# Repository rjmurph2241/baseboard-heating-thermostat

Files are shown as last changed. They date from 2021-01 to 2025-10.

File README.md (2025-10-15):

# ESPHome Based Line Voltage (Baseboard Heating) Thermostat From Wall Switch
A while back, I wanted to add smart thermostats to my apartment.  However, I was surprised by the lack of inexpensive, line voltage (or baseboard) smart thermostats.  Especially since there's so many cheap smart wall switches, and a line voltage thermostat is just a wall switch with a temperature sensor and some type of UI.  So I decided to make some using [ESPHome](esphome.io) and [Home Assistant](home-assistant.io).  At the time, most smart switches used an ESP8266 so I designed a thermostat that could take advantage of the microcontroller that came with the switch.  I've since moved to a house with central heat but has a baseboard heater in the bathroom.  I wanted to be able to run the heater on a timer for showers in the winter so I redesigned the thermostat to use a ESP32 for the increased I/O to add buttons instead of the rotary encoder.

### A couple of notes/warnings:

1. :warning:**Warning**:warning: This project involves line voltage, which can be extremely dangerous and deadly.  I am not an electrician or electrical engineer so proceed at your own risk.  Always turn off the power at the breaker and ~~double~~ triple check the power is disconnected before touching any wires.
1. This project uses inexpensive smart switches.  They are technically rated for 10A but the quality control on the relays is probably not great, so I wouldn't recommend pushing the rating.  If you're worried or your heater is close to the rating, an option would be to replace the relay with something of higher quality.
1. Most smart switches no longer use an ESP as their microcontroller so you may have to replace the whole control board anyway.  [ESPHome](esphome.io) now supports the BK72xx and RTL87xx but I haven't played around with them at all so I have no idea if they could work.  ESPs are inexpensive so my recommendation, even for the rotary encoder version, would be to just replace the control board with your own ESP and save the headache.
1. I designed the covers in a CAD program called [Alibre Atom 3D](https://www.alibre.com/atom3d/).  It's not very widely used (I've never met anyone else who uses it) but it's functional, keeps everything local, and inexpensive.  I've uploaded the CAD files on the off-chance someone else uses Alibre, but .STP and .STL files are available on [Printables](https://www.printables.com/model/1037639-smart-baseboard-heater-thermostat).

## Instructions Here:

[**Rotary Encoder**](/rotary-encoder/Rotary-Encoder.md) | [**Six Buttons**](/six-buttons/Six-Buttons.md)
:--------------------------------------------------:|:----------------------------------------------------------:
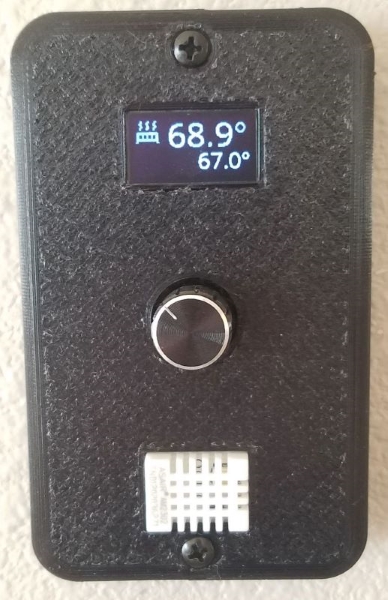
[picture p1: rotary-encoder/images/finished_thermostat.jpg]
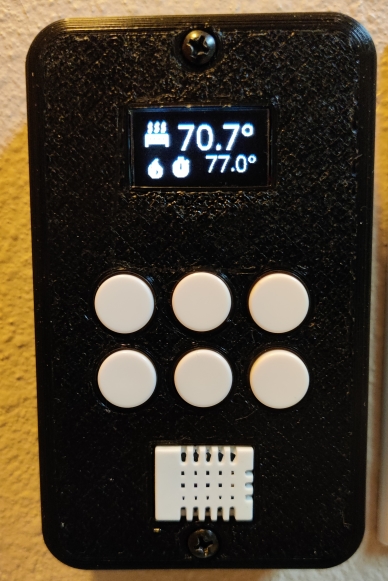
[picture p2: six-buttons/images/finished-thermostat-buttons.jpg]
  |

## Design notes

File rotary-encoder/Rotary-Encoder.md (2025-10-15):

# Rotary Encoder Thermostat from Smart Switch

## :warning:***Warning***:warning: 
***This project involves line voltage, which can be extremely dangerous and deadly.  I am not an electrician or electrical engineer so proceed at your own risk.  Always turn off the power at the breaker and ~~double~~ triple check the power is disconnected before touching any wires.***



## Parts List ##
1. A ESP based smart wall switch, with accessible GPIO pins.  I used a Laghten smart switch (no longer available).  Others will probably work as well, but most no longer use ESP microcontrollers.
1. A USB-UART (USB to TTL converter) for flashing 
1. DHT22/AM2302 ([Amazon Link](https://www.amazon.com/gp/product/B01JGNL2LM))
1. Rotary encoder with push button ([Amazon Link](https://www.amazon.com/gp/product/B08728K3YB))
1. 128X64 (0.96") SSD1306 OLED display ([Amazon Link](https://www.amazon.com/PEMENOL-Display-0-96inch-Raspberry-Microcontroller/dp/B07F3KY8NF))
1. JST battery connectors (optional)
1. A 4.7K resistor
1. 4x wire nuts (I reused the ones already in the wall)
1. 2X #6 screws for the switch
1. 3D printed case
1. Hot glue gun
1. 2X #6 x 1" decorative wall plate screws (colored to match your 3D printed case)

## Flashing ##
I recommend flashing the ESP before you start soldering parts onto it.  Unfortunately Tuya Convert no longer seems to work due to the new Tuya firmware, so you'll have to use a USB-UART converter and solder connections.  My smart switch was based on a TYWE3S and I used the Tasmota instructions available [here](https://tasmota.github.io/docs/devices/TYWE3S/) for flashing.

:warning: *Power the ESP from 3.3V on the USB-UART during flashing.* ***Do not connect line power during flashing!*** :warning:

I found it easiest to remove the entire board with the ESP from the switch to flash and solder on components.

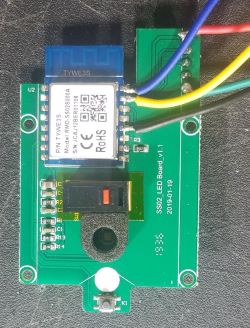
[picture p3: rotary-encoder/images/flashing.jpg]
Flashing


## Soldering Components
Here is the pinout I used.  Other configurations would likely work but I know this one worked for me.

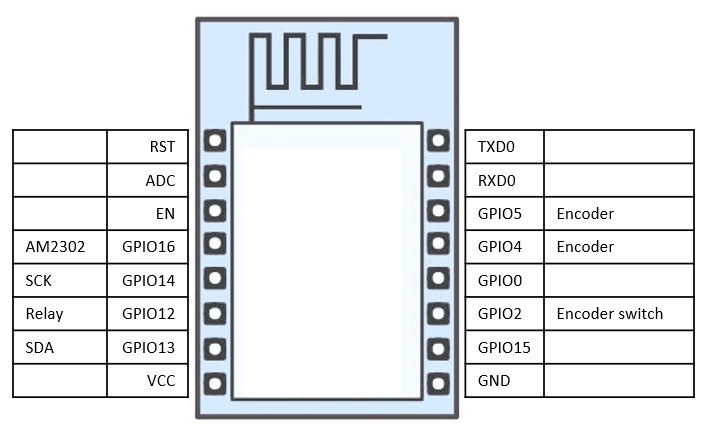
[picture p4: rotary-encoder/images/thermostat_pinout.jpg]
pinout


I also used pre-wired JST connectors to make removing the cover easier once all the components were soldered together and I used sharpie to color code the different connections.

JST Connectors

You also need to de-solder the microswitch or the encoder won't fit.  Save it along with the front plates if you ever want to change it back to a wall switch.

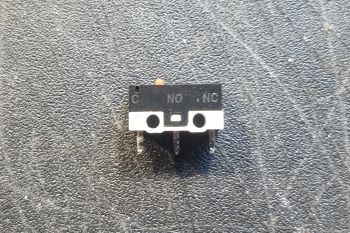
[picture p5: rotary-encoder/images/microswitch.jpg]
microswitch


### OLED Display
In order to get the OLED display to fit into the case, I de-soldered the header pins from the board and just soldered the wires directly onto the back.

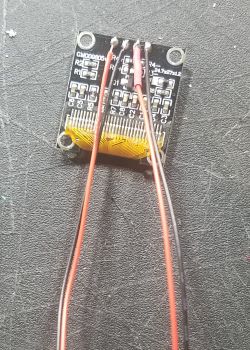
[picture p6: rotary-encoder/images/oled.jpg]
OLED


### Temperature Sensor
The AM2302 requires a pull-up resistor on the data line, so that was soldered on first along with the data wire.  Then the power wires were added.

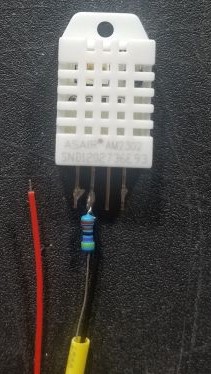
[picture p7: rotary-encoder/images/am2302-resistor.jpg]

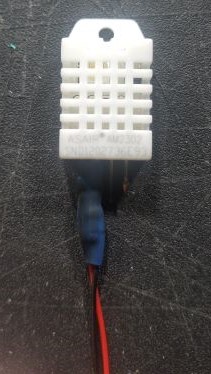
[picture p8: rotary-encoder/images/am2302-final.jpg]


You could also buy the kind that come on the circuit board, which already has the pull-up resistor.

### Rotary Encoder
The encoder has 2 separate connections.  The encoder and the push button.  For the push button, one connection should be GND and the other connected to an GPIO pin.  For the encoder portion, the center pin should be GND and the other two connected to GPIO pins.  I connected the two GND connections at the encoder and only ran one wire back to the ESP's GND.

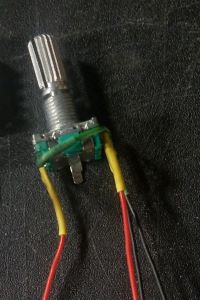
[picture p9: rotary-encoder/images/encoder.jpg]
encoder


### Case
The case was designed in Alibre Atom 3D.  I've included the [original file](/rotary-encoder/thermostat_cover_rotary_encoder.AD_PRT) as well as the .stl and STEP files (on [Printables](https://www.printables.com/model/1037639-smart-baseboard-heater-thermostat)) if anyone wants to modify them.  I printed mine on my Ender 3V2 in black PETG.  You can print it either face up or face down.  Face up requires a lot more filament for supports but gives you a better front surface.  Face down, you still need supports for where the rotary encoder goes.

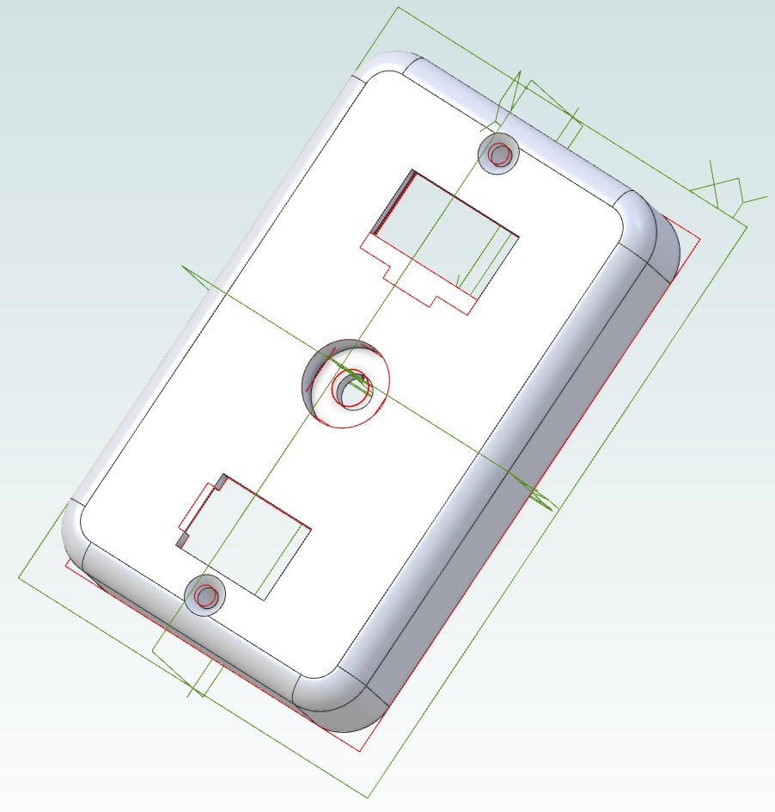
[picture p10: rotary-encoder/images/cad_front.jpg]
case


## Putting It All Together
Before gluing or closing anything up, it's always good to do a quick test to make sure all your connections are secure.

**:warning: When testing using line voltage, always put wire nuts over any unconnected wires (switched wire) and never touch any exposed connections! :warning:**

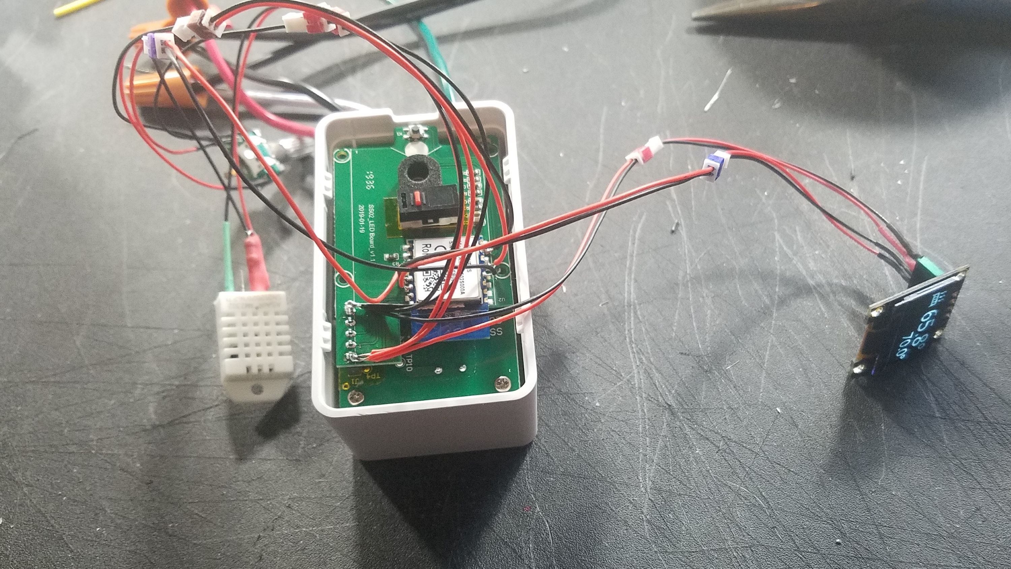
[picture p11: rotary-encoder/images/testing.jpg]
testing


(This image was taken before I realized the microswitch didn't fit.)

I like to try and make things as re-usable as possible so I prefer to use hot glue to hold everything together.  

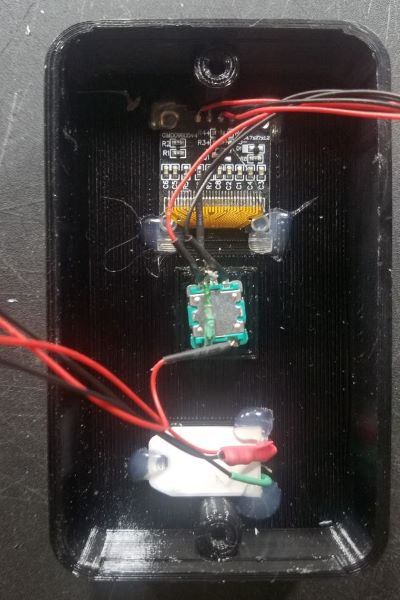
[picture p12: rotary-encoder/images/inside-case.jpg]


### Installing It On The Wall
As I am not an electrician, I don't want to give detailed instructions on how to install the high voltage aspects.  The basics of installing the thermostat are:
1. :warning: Make sure the power is turned off at the breaker :warning:
1. :warning: Check again that the power is turned off :warning:
1. :warning: Use a non-contact voltage tester to make sure theres no power! (Seriously this is important!) :warning:
1. Connect the wires appropriately.
1. Screw in the switch

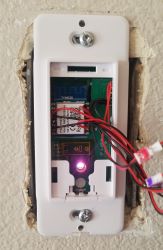
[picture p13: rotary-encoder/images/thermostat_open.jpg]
	
1. Connect the 3.3V and data cables to the components in the 3D printed case.
1. Screw on the 3D printed case
1. Cross your fingers & turn back on the power

### YAML Configuration

You'll need to set the substitutions at the top of the YAML file before you flash using ESPHome.  You'll also need to set your wifi_ssid, wifi_password, api_encryption (key) and ota_password in your secrets file.  More information on the secrets file is in the [ESPHome documentation](https://esphome.io/guides/faq.html)

## Thermostat Operation
The thermostat will work even when disconnected from Home Assistant.  
1. To change the temperature, you short press the rotary encoder and you can adjust the temperature set-point in 0.1<sup>o</sup> increments.  Another short press sets the new set-point.  If the thermostat is in "Set Temperature" mode, the thermometer icon will be displayed. 
1. To toggle the thermostat on or off, simply long press the rotary encoder. The radiator symbol will toggle between the "off" and "on" versions.  
1. The thermostat will display the flame icon while the heater is running.

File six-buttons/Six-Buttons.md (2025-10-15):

# Button Thermostat from Smart Switch

## :warning:***Warning***:warning: 
***This project involves line voltage, which can be extremely dangerous and deadly.  I am not an electrician or electrical engineer so proceed at your own risk.  Always turn off the power at the breaker and ~~double~~ triple check the power is disconnected before touching any wires.***



## Parts List ##
1. A inexpensive smart switch.
1. A ESP32 which fits in the case.  I used a D1 Mini ESP32. ([Amazon Link](https://www.amazon.com/s?k=ESP32+D1+mini))
1. DHT22/AM2302 ([Amazon Link](https://www.amazon.com/gp/product/B01JGNL2LM))
1. 6X 12x12x7.3mm momentary buttons ([Amazon Link](https://www.amazon.com/gp/product/B07CG7VTGD/))
1. Prototypeing PCB Board ([Amazon Link](https://www.amazon.com/s?k=prototype+PCB+board))
1. 128X64 (0.96") SSD1306 OLED display ([Amazon Link](https://www.amazon.com/PEMENOL-Display-0-96inch-Raspberry-Microcontroller/dp/B07F3KY8NF))
1. KF2510 Wire Connectors (Optional) ([Amazon Link](https://www.amazon.com/s?k=KF2510))
1. 4x wire nuts (I reused the ones already in the wall)
1. 2X #6 screws for the switch
1. 3D printed case
1. Hot glue gun
1. 2X #6 x 1" decorative wall plate screws (colored to match your 3D printed case)

## Soldering Components ##

### Case and ESP ###

In order to fit, the wires need to be soldered directly to the ESP without headers.  Then I used some 90<sup>o</sup> headers to connect to the 3.3V, GND, and switch I/O from the smart switch and hot-glued the ESP32 in place.

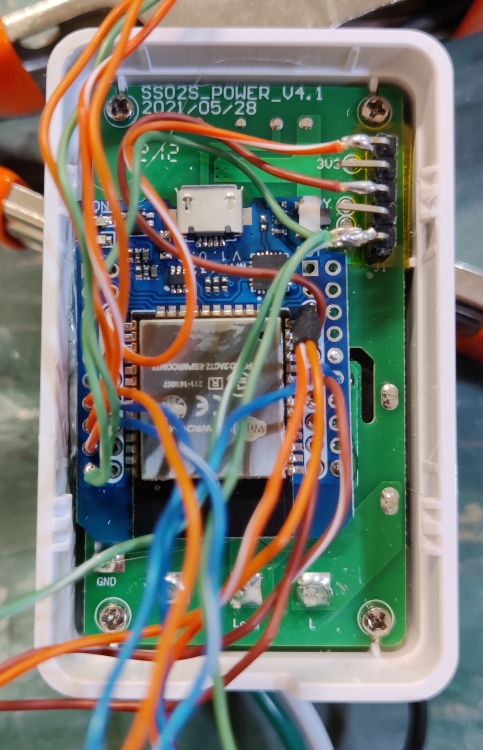
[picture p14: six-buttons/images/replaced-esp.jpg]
 

I connected the buttons, screen, and AM2302 with KF2510 connectors to make everything easy to assemble and take apart.  You could also just solder everything directly but it would probably be unwieldy.

### Buttons ###

I wired the buttons in a pull-up configuration (so they pulled to ground when pressed).  In order to fit the case they need to be soldered on a 0.6 in (15.24 mm) grid, which works out to 7 solder points center to center.

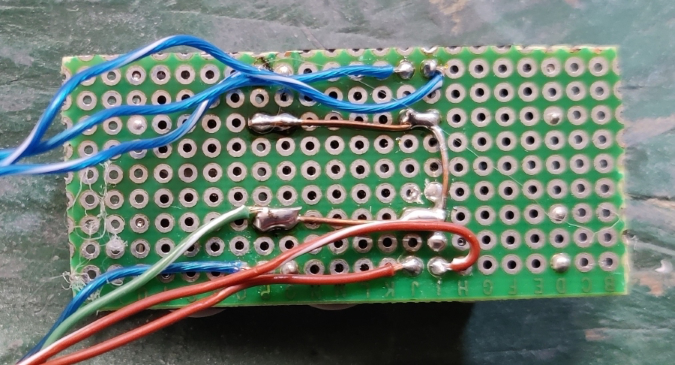
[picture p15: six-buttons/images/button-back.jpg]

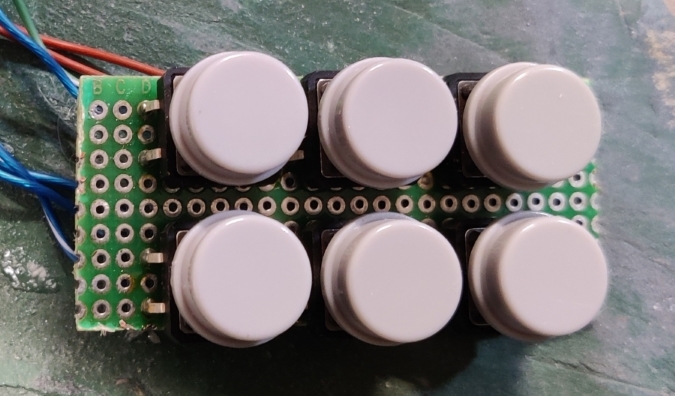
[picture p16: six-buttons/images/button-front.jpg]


### OLED Display
In order to get the OLED display to fit into the case, I de-soldered the header pins from the board and just soldered the wires directly onto the back.

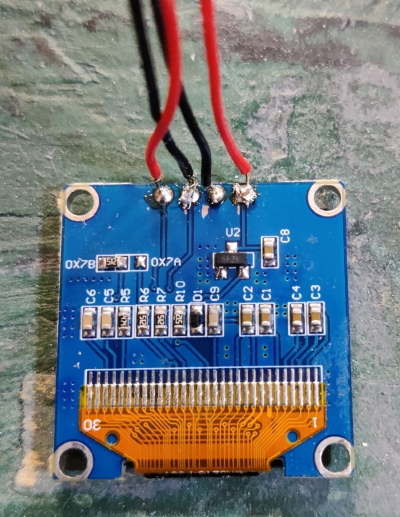
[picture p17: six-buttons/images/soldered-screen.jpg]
OLED


### Case ###
The case was designed in Alibre Atom 3D.  I've included the [original file](/six-buttons/thermostat_cover_buttons.AD_PRT) as well as the .stl and STEP files (on [Printables](https://www.printables.com/model/1037639-smart-baseboard-heater-thermostat)) if anyone wants to modify them.  I printed mine on my Ender 3 Pro in black PETG.  You can print it either face up or face down.  Face up requires a lot more filament for supports but gives you a better front surface.

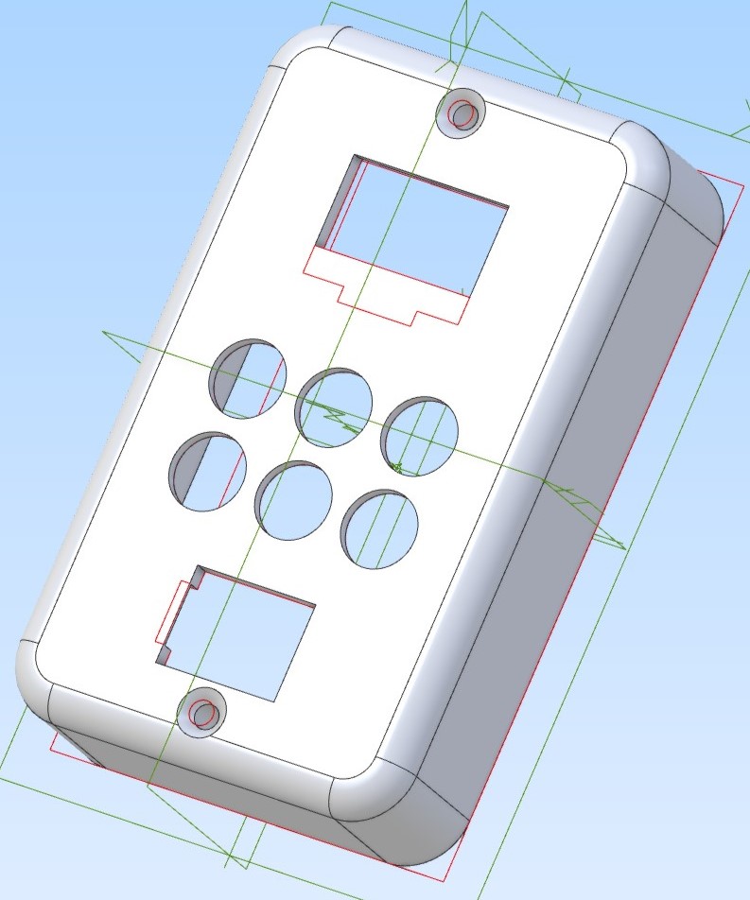
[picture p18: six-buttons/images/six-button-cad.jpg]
case


## Putting It All Together
I like to try and make things as re-usable as possible so I prefer to use hot glue to hold everything together.  

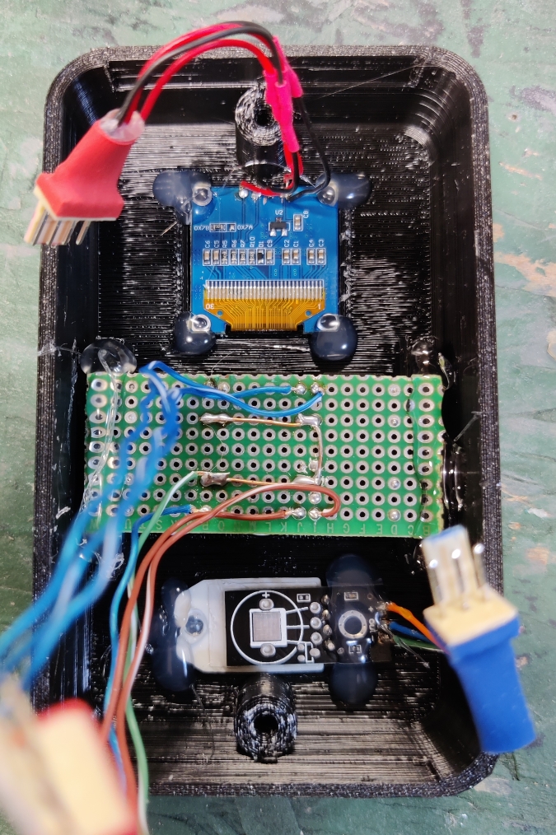
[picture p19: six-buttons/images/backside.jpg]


Before gluing or closing anything up, it's always good to do a quick test to make sure all your connections are secure.

**:warning: When testing using line voltage, always put wire nuts over any unconnected wires (switched wire) and never touch any exposed connections! :warning:**

### Installing It On The Wall
As I am not an electrician, I don't want to give detailed instructions on how to install the high voltage aspects.  The basics of installing the thermostat are:
1. :warning: Make sure the power is turned off at the breaker :warning:
1. :warning: Check again that the power is turned off :warning:
1. :warning: Use a non-contact voltage tester to make sure theres no power! (Seriously this is important!) :warning:
1. Connect the wires appropriately.
1. Screw in the switch
1. Connect the 3.3V and data cables to the components in the 3D printed case.
1. Screw on the 3D printed case
1. Cross your fingers & turn back on the power

### YAML Configuration

You'll need to set the substitutions at the top of the YAML file before you flash using ESPHome.  You'll also need to set your wifi_ssid, wifi_password, api_encryption (key) and ota_password in your secrets file.  More information on the secrets file is in the [ESPHome documentation](https://esphome.io/guides/faq.html)

## Thermostat Operation
- The thermostat will work even when disconnected from Home Assistant.  
- The large number is the current temperature and the small number is the set-point.
- The thermostat will toggle between the radiator off and radiator on symbol depending on it's state.
- The thermostat will display the flame icon while the heater is running.
- The thermostat will display the clock icon if the timer is running.

There are six buttons, I currently have them set to:

Temperature up (by 0.5 <sup>o</sup>)|Toggle On/Off|30 minute timer
:--:|:--:|:--:
**Temperature down (by 0.5 <sup>o</sup>)** | **Toggle preset (Toggle between 69<sup>o</sup> and 77<sup>o</sup> )** | **1 hour timer**

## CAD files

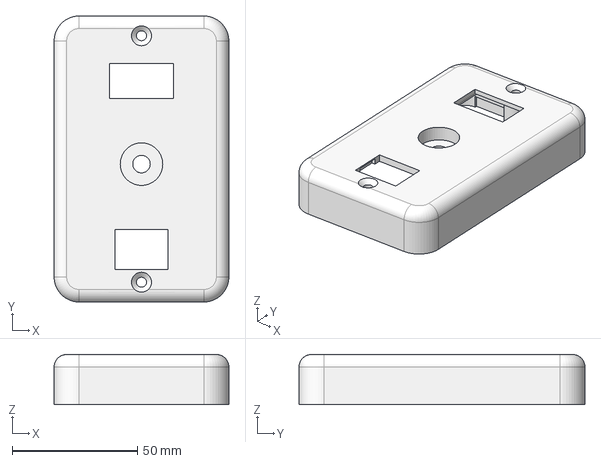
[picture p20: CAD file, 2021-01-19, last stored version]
images/thermostat cover.stp
69.8 x 114.3 x 20.0 mm

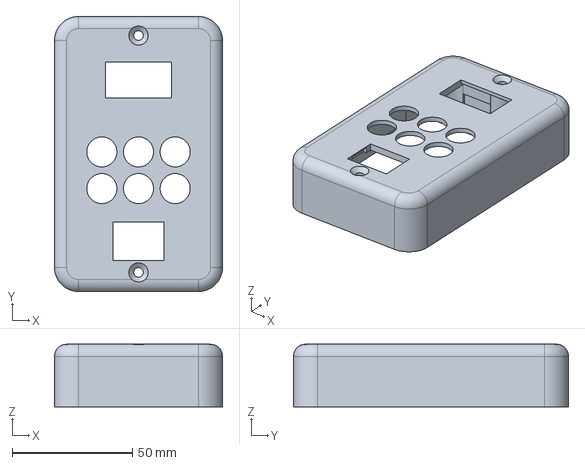
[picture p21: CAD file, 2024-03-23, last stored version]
six-buttons/thermostat_cover_buttons.stp
69.8 x 114.3 x 26.0 mm

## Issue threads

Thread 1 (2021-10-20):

unknown tag !<!lambda>

den3537, 2021-10-20:
gives this error  unknown tag !<!lambda> at line 44, column 69:  ... m).target_temperature_low * 18;"
home assistant
 core-2021.10.6
supervisor-2021.10.0
how can i fix it?

rjmurph2241, 2021-11-01:
It looks like you are using the Home Assistant file editor.  You should be doing everything through the ESPHome interface.  Create a new device there then copy the code into the new device.

den3537, 2021-11-01:
Thanks. works

Closed 2021-11-01.

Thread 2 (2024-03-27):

Fix README.md link to six buttons page

jcormier, 2024-03-27:
s/Six-Buttons.md/Six-Button.md/

rjmurph2241, 2024-03-29:
Fixed, thanks!

Closed 2024-03-29.

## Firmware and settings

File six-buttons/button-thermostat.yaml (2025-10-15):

substitutions:
  devicename: "button-thermostat"
  thermostat_name: "Button Thermostat"
  offset: "0"
  kwatts: '1'
  sda_pin: '26'
  scl_pin: '18'
  dht_pin: '33'
  relay_pin: '5'
  temp_up_pin: '22'
  temp_down_pin: '32' 
  mode_pin: '21' 
  preset_pin: '25'
  min30_pin: '17'
  hr1_pin: '27' 

esphome:
  name: $devicename
  friendly_name: $thermostat_name

esp32:
  board: wemos_d1_mini32
  
wifi:
  ssid: !secret wifi_ssid
  password: !secret wifi_password
  ap:
    ssid: ${devicename}_fallback
    password: !secret wifi_password

captive_portal:

# Enable logging
logger:

# Enable Home Assistant API
api:
  #password: !secret api_password
  encryption:
    key: !secret api_encryption

ota:
  password: !secret api_password

time:
  - platform: homeassistant
    id: homeassistant_time

globals: #create global variable to pass subsitution to lambda in template sensor
  - id: heater_power #used to determine the power usage of the heater
    type: int
    restore_value: no
    initial_value: $kwatts
  #timer variables; used to set how long the timer should run
  - id: timer_count
    type: int
    restore_value: no
    initial_value: '360'

script:
  id: timer #script to run thermostat on a timer
  mode: restart
  then:
    #turn on thermostat
    - climate.control:
        id: therm
        mode: "HEAT"
    - while:
        condition:
          lambda: |-
            return id(timer_count)> 0;
        then:
        - delay: 1s
        - lambda: |-
            id(timer_count) -= 1;
    #turn off thermostat
    - climate.control:
        id: therm
        mode: "OFF"

sensor:
  - platform: dht
    model: AM2302
    pin: 
      number: $dht_pin
    temperature:
      id: temp
      filters:
        - offset: $offset
        - median:
            window_size: 4
            send_every: 4
            send_first_at: 2
    update_interval: 3.1s
  # current power usage sensor
  - platform: template
    id: power
    name: ${thermostat_name} Power
    internal: true
    update_interval: 1s
    unit_of_measurement: kW
    lambda: |-
      if (id(heater).state) {
      return id(heater_power);
      } else {
      return 0;
      }
  # daily energy usage sensor
  - platform: total_daily_energy
    name: ${thermostat_name} Daily Energy
    power_id: power

switch:
  #heater
  - platform: gpio
    pin: $relay_pin
    id: heater
    restore_mode: always_off

binary_sensor: #buttons
  #temp up
  - platform: gpio
    id: pin1
    pin:
      number: $temp_up_pin
      mode: INPUT_PULLUP
      inverted: true
    filters: 
      - delayed_on_off: 10ms
    on_press:
      - lambda: |-
          auto call = id(therm).make_call();
          call.set_target_temperature(id(therm).target_temperature + 0.2778);
          call.perform();
  #temp down
  - platform: gpio
    id: pin2
    pin:
      number: $temp_down_pin
      mode: INPUT_PULLUP
      inverted: true
    filters: 
      - delayed_on_off: 10ms
    on_press:
      - lambda: |-
          auto call = id(therm).make_call();
          call.set_target_temperature(id(therm).target_temperature - 0.2778);
          call.perform();    
  #toggle mode
  - platform: gpio
    id: pin3
    pin:
      number: $mode_pin
      mode: INPUT_PULLUP
      inverted: true
    filters:
      - delayed_on_off: 10ms
    on_press:
      then:
      - if:
          condition:
          - script.is_running: timer
          then:
          - script.stop: timer
      - lambda: |-
          auto call = id(therm).make_call();
          if(id(therm).mode == 0) {
            call.set_mode("HEAT");
            //id(heater_mode) = 1;
          }
          else {
            call.set_mode("OFF");
            //id(heater_mode) = 0;
            }
          call.perform();

  #toggle preset
  - platform: gpio
    id: pin4
    pin:
      number: $preset_pin
      mode: INPUT_PULLUP
      inverted: true
    filters: 
      - delayed_on_off: 10ms
    on_press:
      then:
        lambda: |-
          auto call = id(therm).make_call();
          if(id(therm).preset == 1) {
            call.set_preset("AWAY");
          }
          else {
            call.set_preset("HOME");
            }
          call.perform();

  #30 min timer
  - platform: gpio
    id: pin5
    pin:
      number: $min30_pin
      mode: INPUT_PULLUP
      inverted: true
    filters: 
      - delayed_on_off: 10ms
    on_press:
      - lambda: |-
          id(timer_count) = 1800;
      - script.execute: timer
  #1 hour timer
  - platform: gpio
    id: pin6
    pin:
      number: $hr1_pin
      mode: INPUT_PULLUP
      inverted: true
    filters: 
      - delayed_on_off: 10ms
    on_press:
      - lambda: |-
          id(timer_count) = 3600;
      - script.execute: timer
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

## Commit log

2021-01-12 image edits & upload thermostat .stl
2021-01-19 Add cad image
2021-01-19 Create thermostat cover.stp
    [thermostat cover.stp]
2021-01-19 move step file from images
    [thermostat cover.stp]
2021-01-19 rename cad files
    [thermostat_cover.stp]
2024-03-23 Add 6-button version & major clean-up
    Finally got around to adding the 6 button version which required reworking and cleaning up the readme and instructions.
    [thermostat_cover.stp, thermostat_cover_buttons.stp, thermostat_cover_rotary_encoder.stp]
2025-10-15 Update YAML for ESPHome
    ESPHome/Home assistant changed how they handle device names, so updated YAML to support "friendly_name"
    Also moved STLs to Printables
    [thermostat_cover_buttons.stp, thermostat_cover_rotary_encoder.stp]
